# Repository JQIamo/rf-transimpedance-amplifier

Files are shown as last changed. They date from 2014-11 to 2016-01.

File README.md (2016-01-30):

# RF Transimpedance Amplifier

An AC-coupled transimpedance amplifier, for use in (eg) beatnote or PDH locks.

Still a work in progress, more info to come soon.

NOTE: Despite git commit history, the pdh-photodiode branch is more up to date than master for the ac-coupled transimpedance amp (I believe...)

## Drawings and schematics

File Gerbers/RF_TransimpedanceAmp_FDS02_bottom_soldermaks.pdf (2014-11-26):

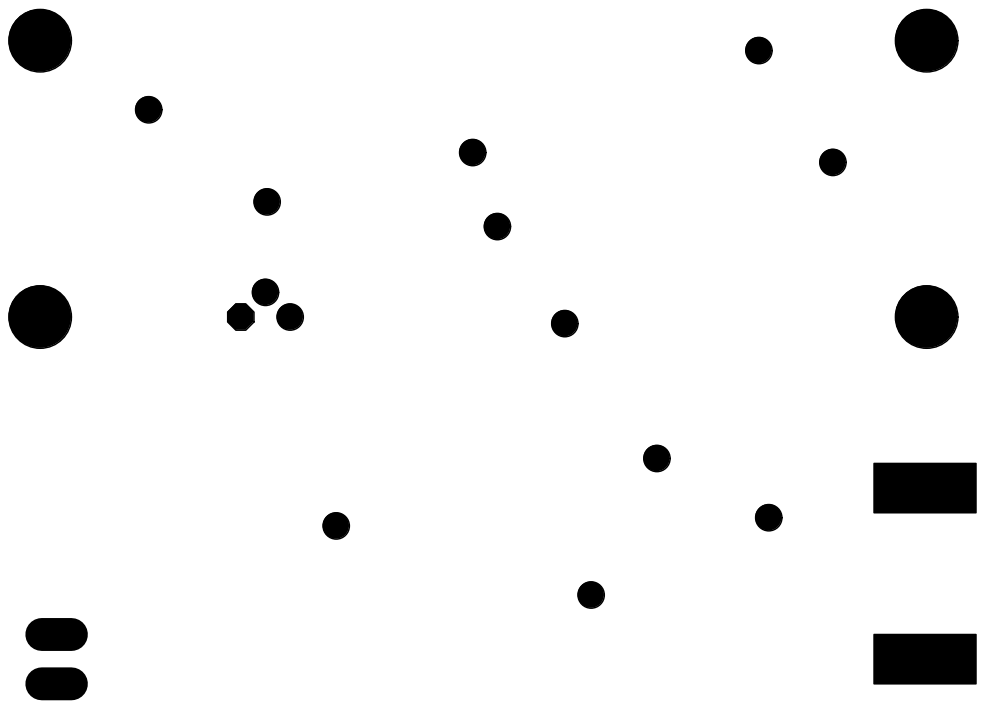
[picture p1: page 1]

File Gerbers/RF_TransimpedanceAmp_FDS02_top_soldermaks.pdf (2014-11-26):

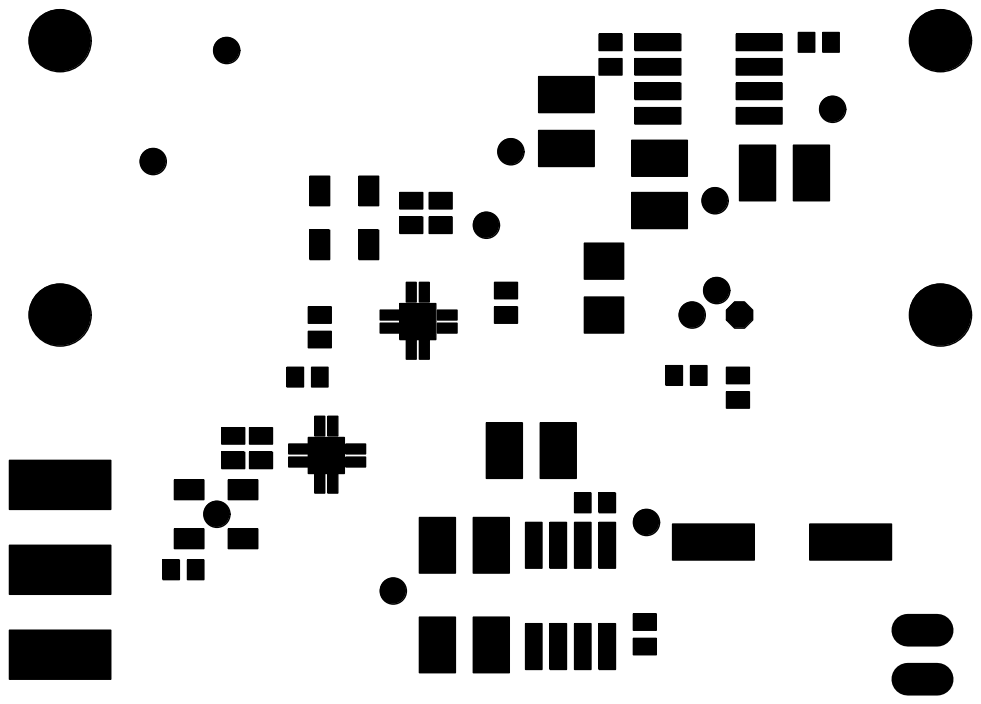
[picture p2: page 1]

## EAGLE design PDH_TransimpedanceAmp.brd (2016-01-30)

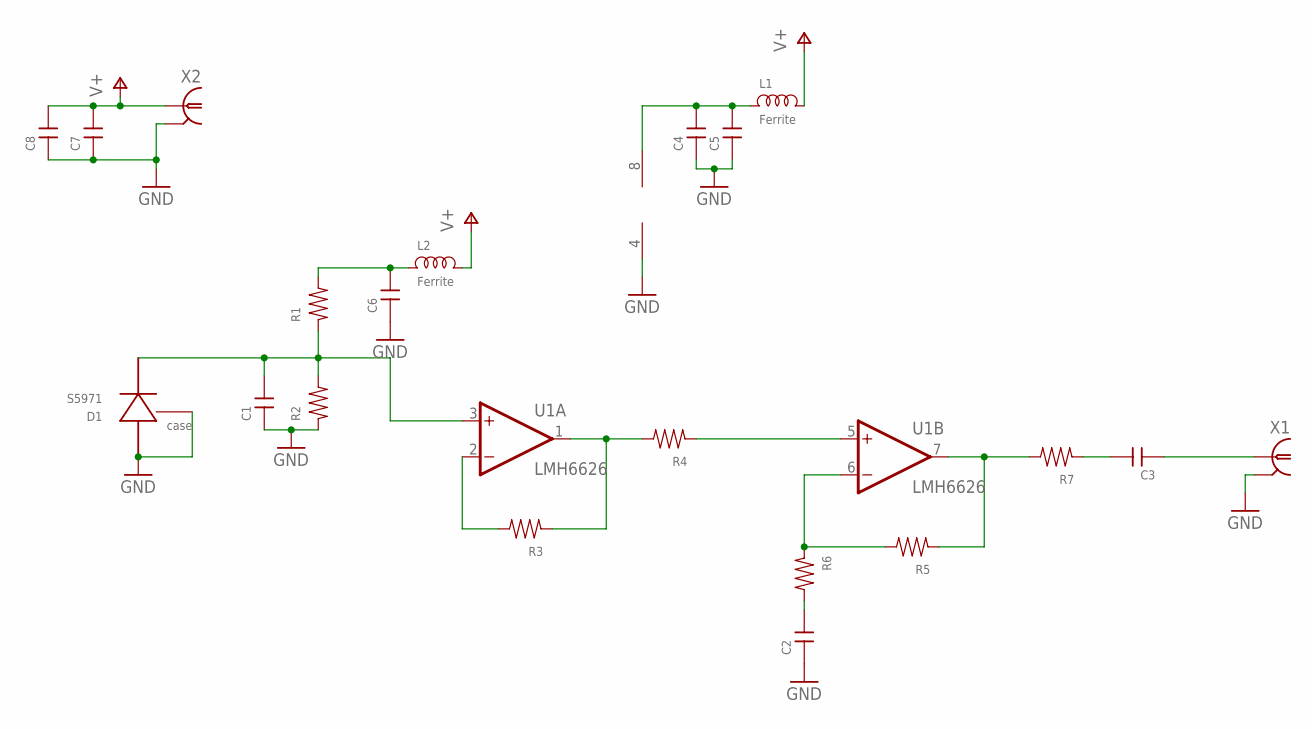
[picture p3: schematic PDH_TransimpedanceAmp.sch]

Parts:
C1, C2, C3, C4, C8: CAP0402; 0402
C5, C6, C7: CAP0805; 0805
D1: S5971; S5971-CASE
L1, L2: Ferrite; 0805
R1, R2, R3, R4, R5, R6, R7: RES0402; 0402
U1: LMH6626; SO08
X1, X2: UMC

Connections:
GND: C1.1, C2.1, C4.1, C5.1, C6.1, C7.1, C8.1, D1.P$2 (CASE), D1.P$3 (ANODE), R2.1, U1.4 (V-), X1.P$2 (2), X1.P$3 (2), X2.P$2 (2), X2.P$3 (2)
unnamed: C1.2, D1.P$1 (CATHODE), R1.1, R2.2, U1.3 (+IN)
unnamed: R5.2, R6.1, U1.6 (-IN)
unnamed: C3.2, R7.1
unnamed: R3.2, U1.2 (-IN)
unnamed: R3.1, R4.2, U1.1 (OUT)
unnamed: R4.1, U1.5 (+IN)
unnamed: C2.2, R6.2
unnamed: R5.1, R7.2, U1.7 (OUT)
unnamed: C6.2, L2.1, R1.2
unnamed: C4.2, C5.2, L1.1, U1.8 (V+)
unnamed: C3.1, X1.P$1 (1)
V+: C7.2, C8.2, L1.2, L2.2, X2.P$1 (1)

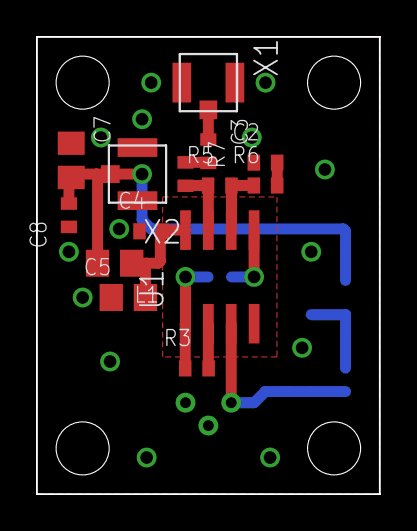
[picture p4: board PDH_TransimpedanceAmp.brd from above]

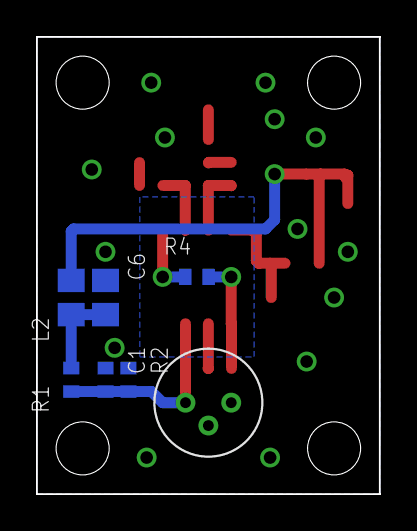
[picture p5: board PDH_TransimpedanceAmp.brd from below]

Board: 2 copper layers, 19.1 x 25.4 mm, 21 parts (7 on the bottom side), 13 nets.

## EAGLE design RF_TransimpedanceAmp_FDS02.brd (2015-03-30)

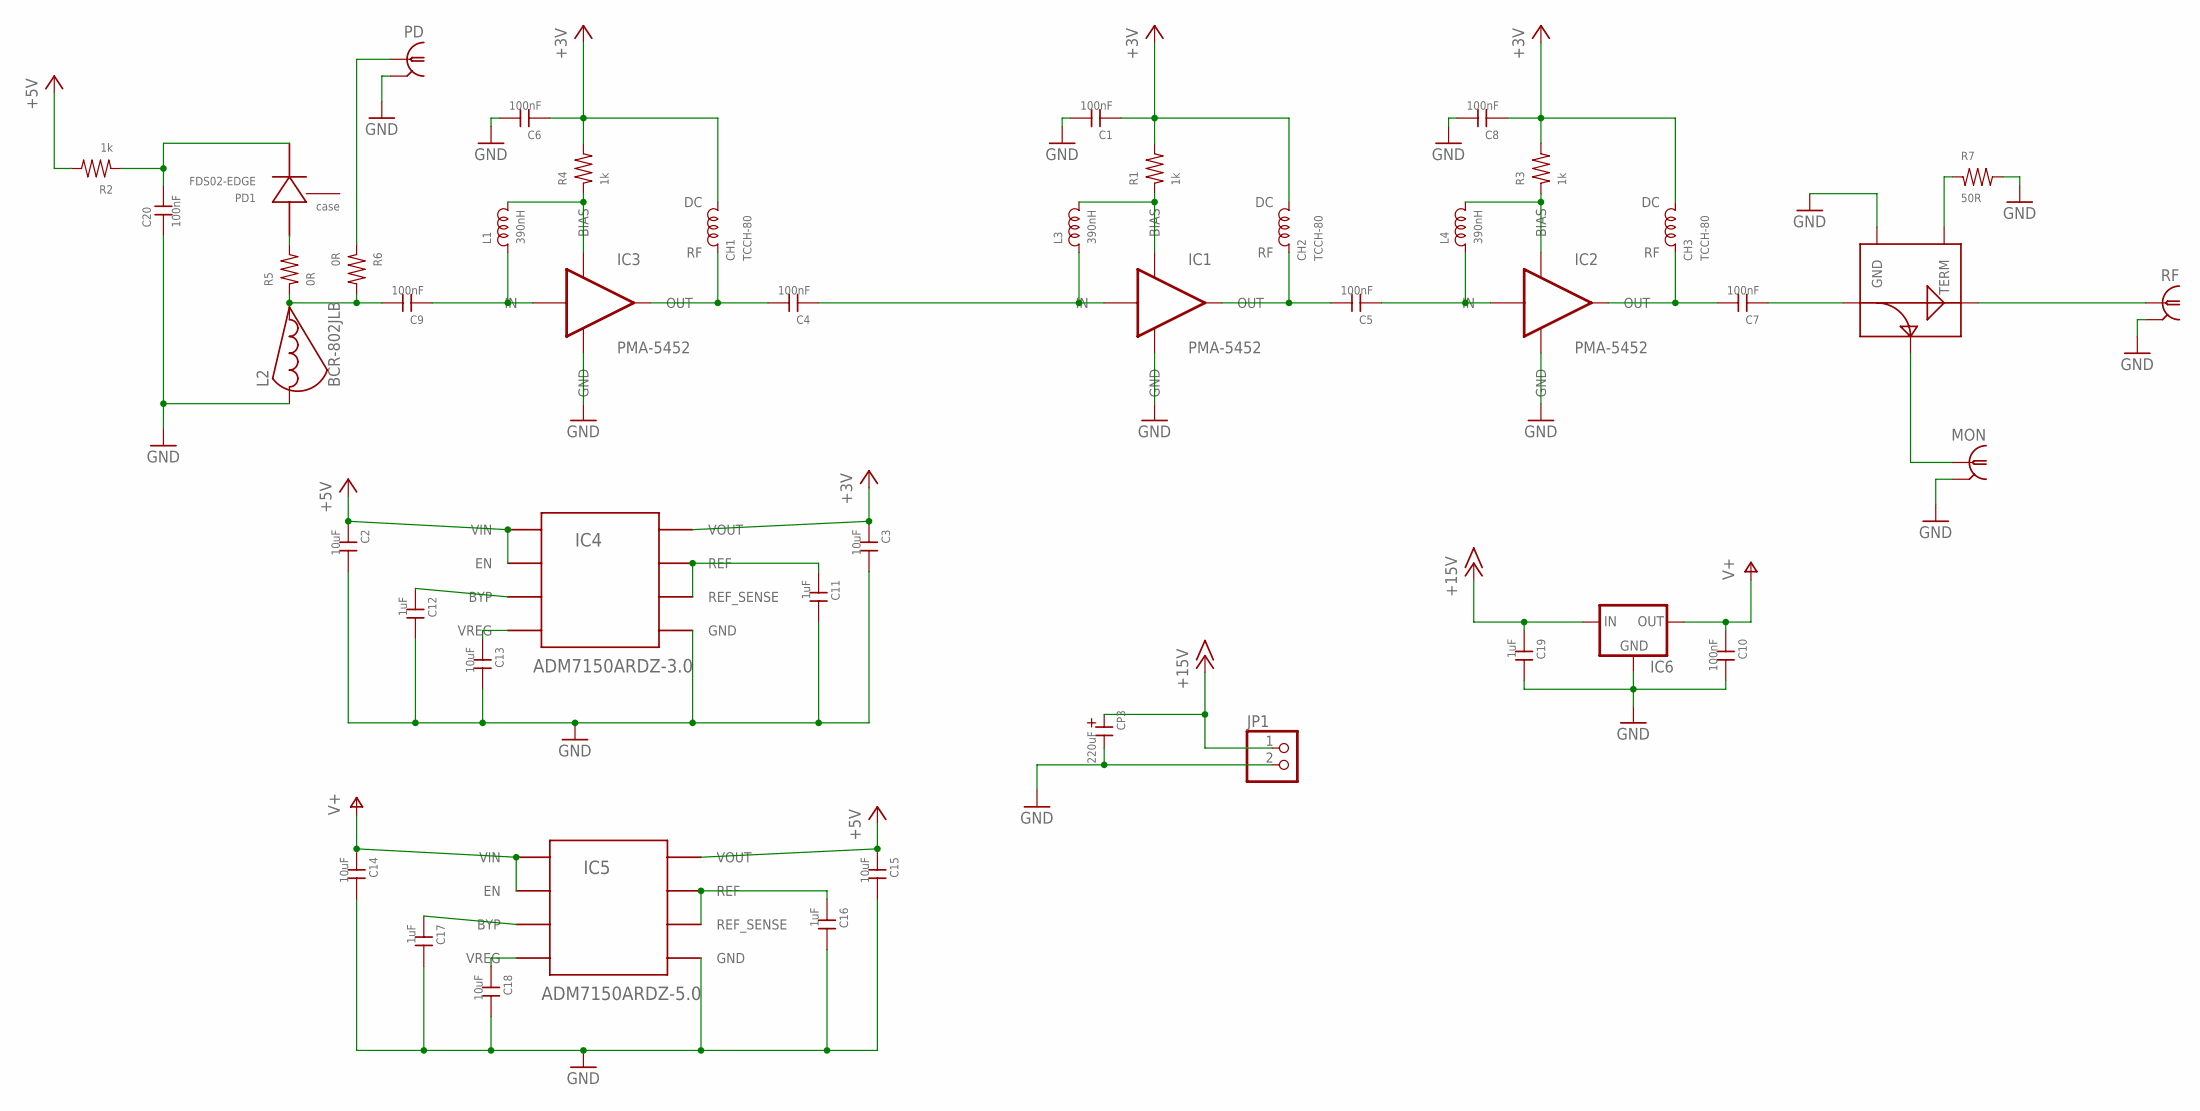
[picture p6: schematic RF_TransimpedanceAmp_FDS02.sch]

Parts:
C1, C4, C5, C6, C7, C8, C9, C20: 100nF; 0402
C2, C3, C13, C14, C15, C18: 10uF; 1210
C10: 100nF; 0603
C11, C12, C16, C17, C19: 1uF; 0603
CH1, CH2, CH3: TCCH-80; GU1604
CP3: 220uF; PANASONIC_F
IC1, IC2, IC3: PMA-5452; DQ849
IC4: ADM7150ARDZ-3.0; SO08
IC5: ADM7150ARDZ-5.0; SO08
IC6: 78XX-TO220; TO220
JP1: PINHD-1X2; 1X02
L1, L3, L4: 390nH; 0402
L2: BCR-802JLB; BCR-MED
MON: SMAJ502-bulkhead; SMA-EDGE; PARTNO CONSMA006.062-ND
PD: SMAJ502-bulkhead; SMA-EDGE; PARTNO CONSMA006.062-ND
PD1: FDS02-EDGE; FDS02-SIDEMOUNT
R1, R2, R3, R4: 1k; 0402
R5, R6: 0R; 0402
R7: 50R; 0603
RF: SMAJ502; SMA-EDGE
U$1: ADC-10-4; BH292

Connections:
+3V: C1.1, C3.1, C6.1, C8.1, CH1.P$3 (DC), CH2.P$3 (DC), CH3.P$3 (DC), IC4.2 (VOUT), R1.2, R3.2, R4.2
+5V: C2.1, C15.1, IC4.7 (EN), IC4.8 (VIN), IC5.2 (VOUT), R2.2
+15V: C19.1, CP3.+, IC6.1 (IN), JP1.1
GND: C1.2, C2.2, C3.2, C6.2, C8.2, C10.2, C11.2, C12.2, C13.2, C14.2, C15.2, C16.2, C17.2, C18.2, C19.2, C20.1, CP3.-, IC1.P$GND (GND), IC2.P$GND (GND), IC3.P$GND (GND), IC4.4 (GND), IC5.4 (GND), IC6.2 (GND), JP1.2, L2.2, MON.G@1 (2), MON.G@2 (2), MON.G@3 (2), MON.G@4 (2), PD.G@1 (2), PD.G@2 (2), PD.G@3 (2), PD.G@4 (2), R7.2, RF.G@1 (2), RF.G@2 (2), RF.G@3 (2), RF.G@4 (2), U$1.P2 (GND)
unnamed: C11.1, IC4.5 (REF_SENSE), IC4.6 (REF)
unnamed: C5.2, CH2.P$1 (RF), IC1.P$6 (OUT)
unnamed: IC1.P$7 (BIAS), L3.2, R1.1
unnamed: RF.1, U$1.P6 (OUT)
unnamed: C20.2, PD1.P$1 (CATHODE), R2.1
unnamed: C4.2, CH1.P$1 (RF), IC3.P$6 (OUT)
unnamed: C9.2, L2.1, R5.1, R6.2
unnamed: C7.2, CH3.P$1 (RF), IC2.P$6 (OUT)
unnamed: IC3.P$7 (BIAS), L1.2, R4.1
unnamed: IC2.P$7 (BIAS), L4.2, R3.1
unnamed: C7.1, U$1.P1 (IN)
unnamed: MON.1, U$1.P3 (COUP)
unnamed: C12.1, IC4.3 (BYP)
unnamed: C13.1, IC4.1 (VREG)
unnamed: C16.1, IC5.5 (REF_SENSE), IC5.6 (REF)
unnamed: PD1.P$3 (ANODE), R5.2
unnamed: PD.1, R6.1
unnamed: C17.1, IC5.3 (BYP)
unnamed: C18.1, IC5.1 (VREG)
unnamed: R7.1, U$1.P4 (TERM)
RFPD: C9.1, IC3.P$1 (IN), L1.1
RFPD1: C4.1, IC1.P$1 (IN), L3.1
RFPD2: C5.1, IC2.P$1 (IN), L4.1
V+: C10.1, C14.1, IC5.7 (EN), IC5.8 (VIN), IC6.3 (OUT)

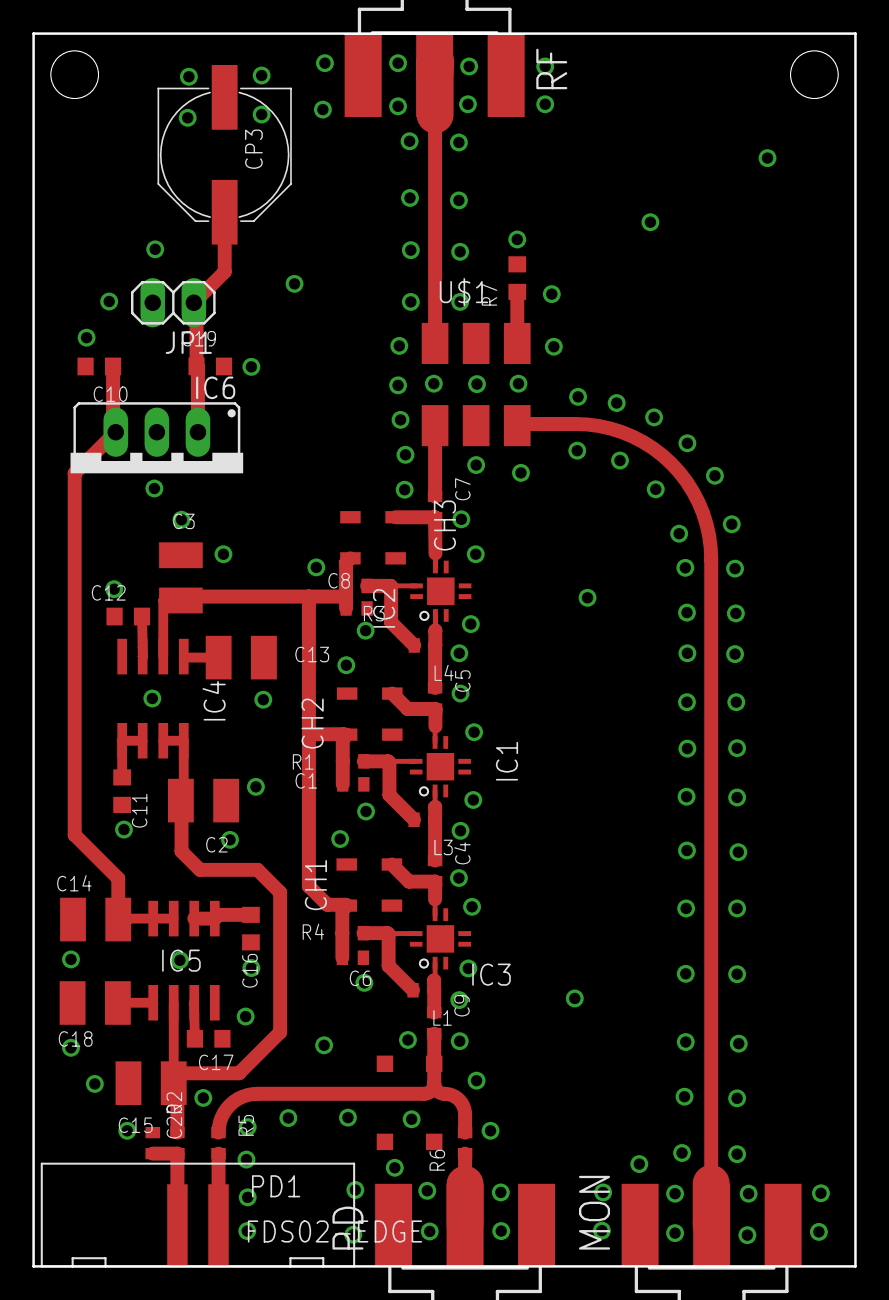
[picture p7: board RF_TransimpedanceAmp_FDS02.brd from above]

Board: 2 copper layers, 50.8 x 76.2 mm, 47 parts (0 on the bottom side), 28 nets.

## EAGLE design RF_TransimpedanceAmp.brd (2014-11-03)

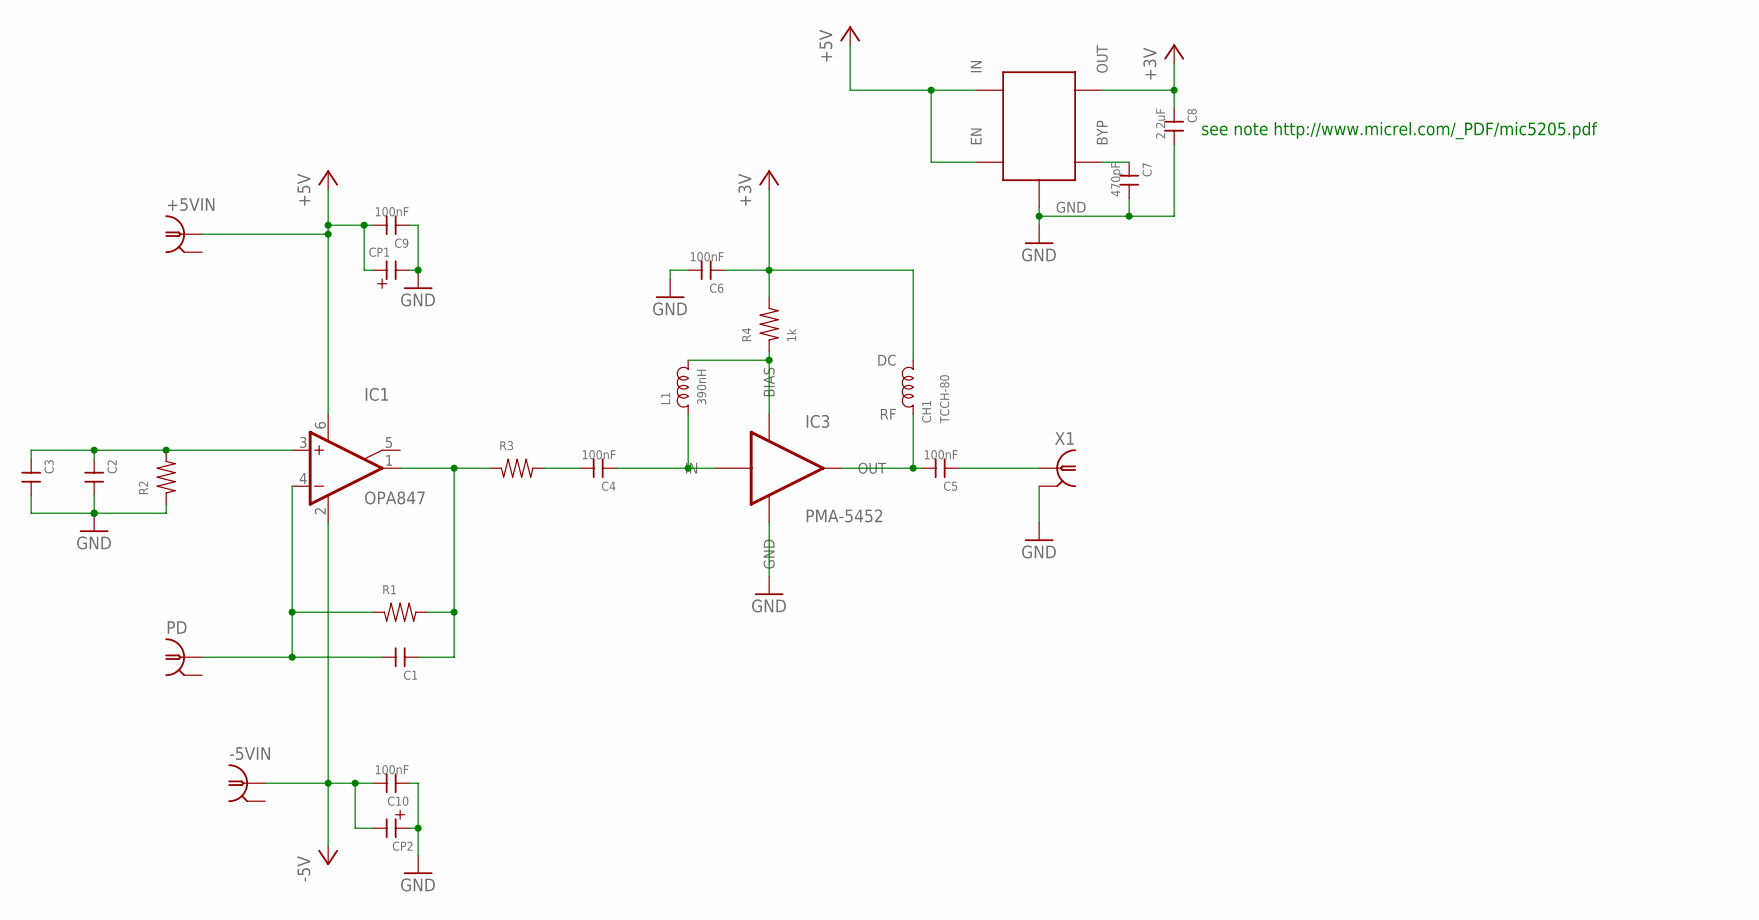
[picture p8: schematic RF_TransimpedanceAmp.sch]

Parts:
+5VIN: UMC
-5VIN: UMC
C1, C2, C3: CAP0201; 0201
C4, C5, C6, C9, C10: 100nF; 0201
C7: 470pF; 0201
C8: 2.2uF; 0402
CH1: TCCH-80; GU1604
CP1, CP2: CAP-POL0603; 0603P
IC1: OPA847; SOT23-6
IC3: PMA-5452; DQ849
L1: 390nH; 0402
PD: SMA; SMA-SMT; DIGIKEY J819-ND
R1, R2, R3: RES0201; 0201
R4: 1k; 0402
U$1: MIC5205; SOT23-5L
X1: UMC

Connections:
+3V: C6.P$1, C8.1, CH1.P$3 (DC), R4.2, U$1.5 (OUT)
+5V: +5VIN.P$1 (1), C9.P$2, CP1.1, IC1.6 (V+), U$1.1 (IN), U$1.3 (EN)
-5V: -5VIN.P$1 (1), C10.P$2, CP2.2, IC1.2 (V-)
GND: C2.P$2, C3.P$2, C6.P$2, C7.P$2, C8.2, C9.P$1, C10.P$1, CP1.2, CP2.1, IC3.P$GND (GND), R2.P$1, U$1.2 (GND), X1.P$2 (2), X1.P$3 (2)
unnamed: C2.P$1, C3.P$1, IC1.3 (+IN), R2.P$2
unnamed: C1.P$2, IC1.4 (-IN), PD.P$1 (1), R1.P$1
unnamed: C1.P$1, IC1.1 (OUT), R1.P$2, R3.P$1
unnamed: C4.P$2, R3.P$2
unnamed: C4.P$1, IC3.P$1 (IN), L1.1
unnamed: C5.P$2, CH1.P$1 (RF), IC3.P$6 (OUT)
unnamed: C5.P$1, X1.P$1 (1)
unnamed: IC3.P$7 (BIAS), L1.2, R4.1
unnamed: C7.P$1, U$1.4 (BYP)

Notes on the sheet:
see note http://www.micrel.com/_PDF/mic5205.pdf

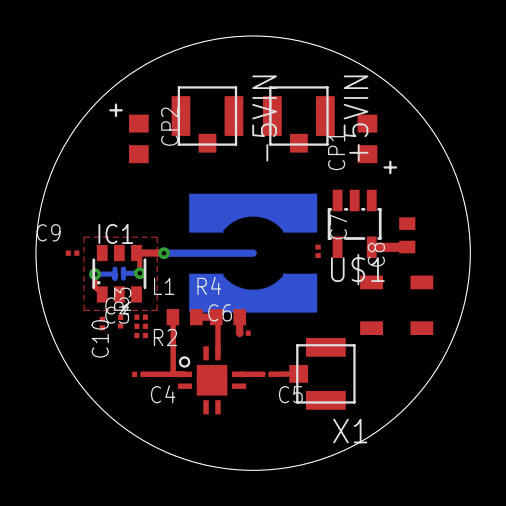
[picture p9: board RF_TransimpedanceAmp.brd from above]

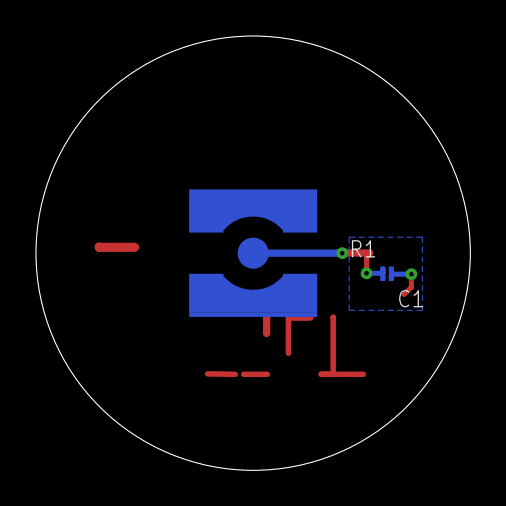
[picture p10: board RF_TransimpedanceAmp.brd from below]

Board: 2 copper layers, 24.1 x 24.1 mm, 25 parts (3 on the bottom side), 13 nets.

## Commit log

2014-11-01 Initial schematic and a bit of layout for an RF transimpedance amplifier.
    [RF_TransimpedanceAmp.brd, RF_TransimpedanceAmp.sch]
2014-11-01 Updated description of how schematic works/plugs together.
2014-11-03 Schematic done; routing in progress. Want to check with alessandro.
    [RF_TransimpedanceAmp.brd, RF_TransimpedanceAmp.sch]
2014-11-21 Initial commit for separate schematic, for Thorlabs FDS02 fiber-connected photodiode
    [RF_TransimpedanceAmp_FDS02.brd, RF_TransimpedanceAmp_FDS02.sch]
2014-11-25 First draft schematic and layout for FDS02 transimpedance amplifier.
    * Low transimpedance gain, followed by low-noise RF amplifier.
    * FDS02 is FC-connectorized, mount on bottom of board and standoff from front panel.
    TODO:
    * Remove -5V supply?
    * Compare OPA847 vs some FET-input op amp
    * Filtering on PD bias voltage?
    [RF_TransimpedanceAmp_FDS02.brd, RF_TransimpedanceAmp_FDS02.sch]
2014-11-25 Minor tweaks to schematic notes; need to check 50 ohm trace width then ready to print.
    [RF_TransimpedanceAmp_FDS02.brd, RF_TransimpedanceAmp_FDS02.sch]
2014-11-25 Adjusted center pad via in RF amp
    [RF_TransimpedanceAmp_FDS02.brd]
2014-11-25 Removed OPA847, using low-noise amplifiers with 50 ohm input as transimpedance gain.
    [RF_TransimpedanceAmp_FDS02.brd, RF_TransimpedanceAmp_FDS02.sch]
2014-11-25 Adjusted grounding vias, created gerbers
    [RF_TransimpedanceAmp_FDS02.brd]
2014-11-26 V0.9 of RF_Transimpedance Amp for FDS02 diode
2014-11-26 Added pdf prints of soldermask, for use with Dynamask 5000 process.
2015-01-19 Added third stage amplifier, fixed layout issues.
    [RF_TransimpedanceAmp_FDS02.brd, RF_TransimpedanceAmp_FDS02.sch]
2015-01-20 Moved mounting hole to rectangular grid
    [RF_TransimpedanceAmp_FDS02.brd]
2015-02-01 Added schematic and board for PDH transimpedance amp.
    For lower RF frequencies; RF amp version only goes to
    50 MHz. This uses an op amp with GBP of 1.5GHz though.
    [PDH_TransimpedanceAmp.brd, PDH_TransimpedanceAmp.sch]
2015-03-20 Ripped up traces in preparation for adding additional SMA and switch for beatnote
    [RF_TransimpedanceAmp_FDS02.brd]
2015-03-22 Added SMA photodiode input; output monitor
    Switch between FDS02 or other photodiode by soldering 0ohm jumper.
    [RF_TransimpedanceAmp_FDS02.brd, RF_TransimpedanceAmp_FDS02.sch]
2015-03-30 minor tweaks to board layout
    [RF_TransimpedanceAmp_FDS02.brd]
2016-01-30 Added AC-coupled transimpedance amp for PDH
    [PDH_TransimpedanceAmp.brd, PDH_TransimpedanceAmp.sch]
